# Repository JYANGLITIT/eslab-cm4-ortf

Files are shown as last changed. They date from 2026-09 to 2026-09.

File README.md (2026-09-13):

# ESLab CM4 ORTF v1.1

A compact indoor stereo microphone mount for two Line Audio CM4 microphones, with a fixed nominal ORTF layout, PETG-CF frame and replaceable TPU 95A suspension/liners.

**Free downloads for non-commercial use — CC BY-NC-ND 4.0. No commercial license is granted.** Credit ESLab (Eternal Sound Lab), retain the attribution and license; do not distribute modified versions. See [NOTICE](NOTICE.md) and [license](LICENSE.txt).

## Cable compatibility — required

**Use L-shaped / right-angle 3-pin XLR female connectors at BOTH microphones. Straight XLR connectors interfere with each other in this layout and are not supported.** This restriction was identified by the owner during a V1.0 physical trial on 13 September 2026 and also applies to V1.1, whose only geometry change is the base lettering. Right-angle connector body sizes and cable exit orientations vary; verify clearance with your chosen connectors. No specific cable brand or length has been validated. Keep the cables slack to avoid constraining the suspension.

**接线要求：两只麦克风端都需使用 L 型／直角三芯 XLR 母头。直头会相互干涉，不适用。** 这是 V1.0 实物试装发现的限制，V1.1 仅增加底座刻字，因此同样适用。L 头外壳尺寸与出线方向不同，请核对所选接头的净空；目前未验证具体品牌或长度。

[▶ Watch the 28-second V1.0 physical assembly / quick-release demo](v1.0-physical-demo.mp4) · [28 秒实拍拆装视频](v1.0-physical-demo.mp4)

## V1.0 physical photographs

Photos supplied by the designer on 13 September 2026. These show the assembled **V1.0** mount, without the ESLab / CM4 lettering added in V1.1. The photos show microphones with cables disconnected; they do not demonstrate a particular L-shaped connector fit.

实拍为 **V1.0（未刻字版）**，下载 V1.1 仅增加底座刻字。照片中麦克风未接线，L 型接线要求来自设计者另外的实际试装反馈。

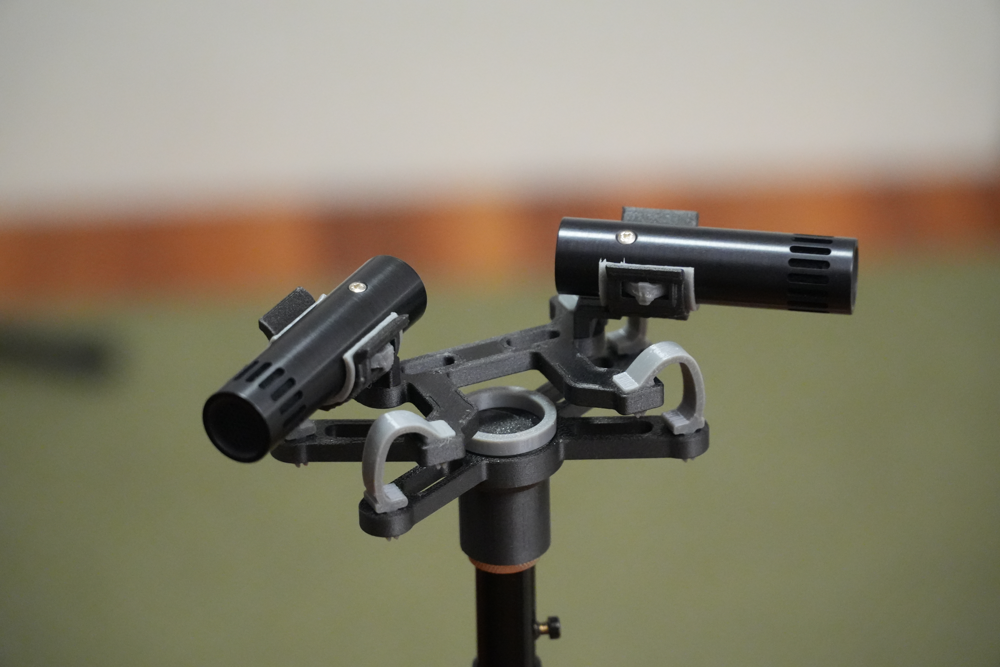
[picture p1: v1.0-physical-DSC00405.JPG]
V1.0 physical print DSC00405


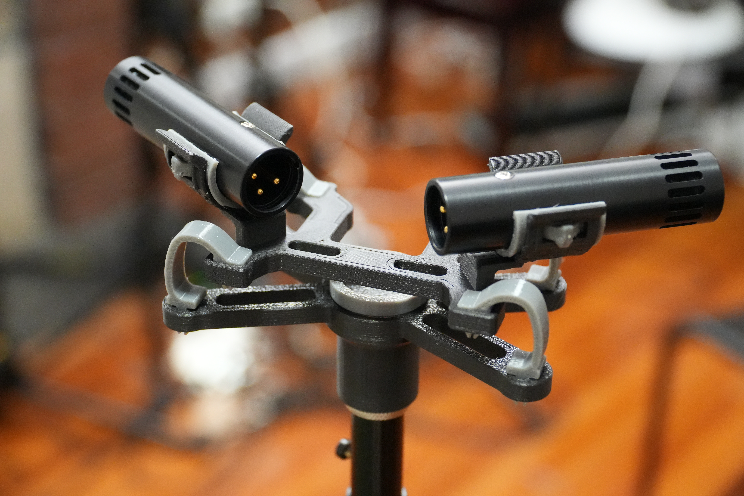
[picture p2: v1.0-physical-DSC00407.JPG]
V1.0 physical print DSC00407


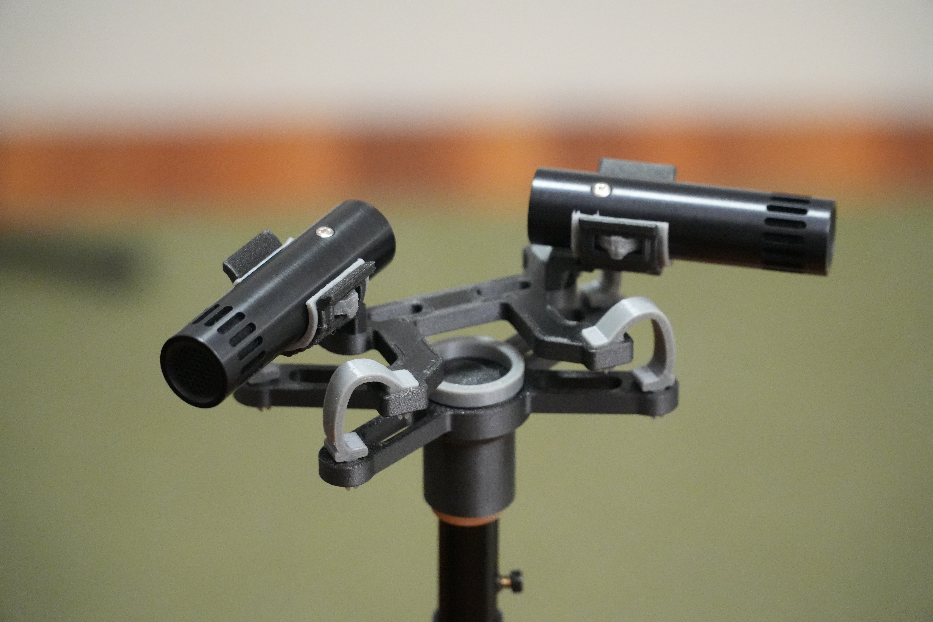
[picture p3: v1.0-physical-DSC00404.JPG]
V1.0 physical print DSC00404


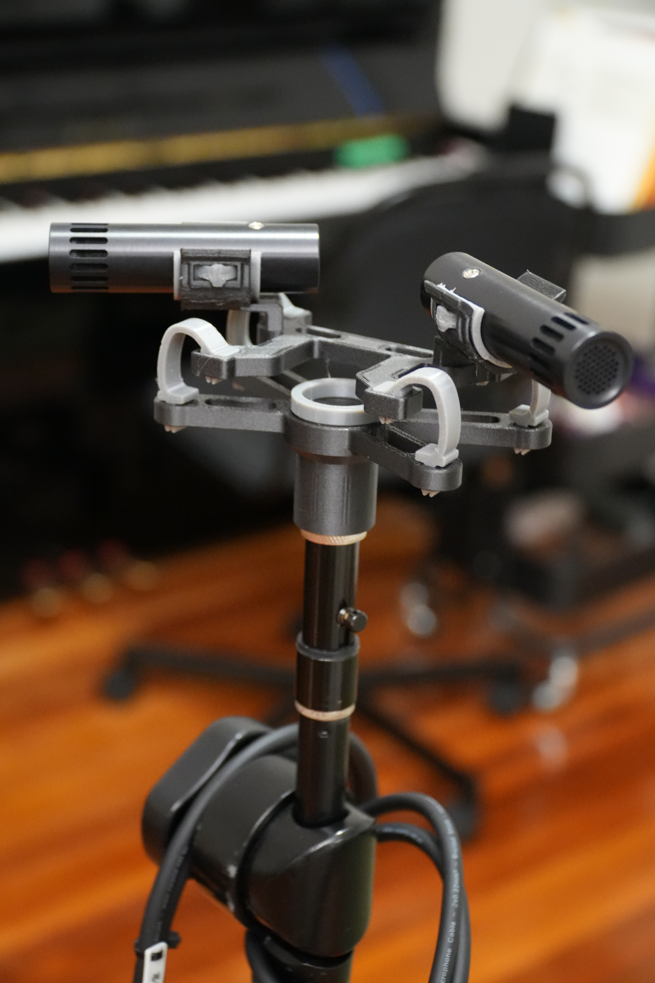
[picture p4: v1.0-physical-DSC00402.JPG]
V1.0 physical print DSC00402


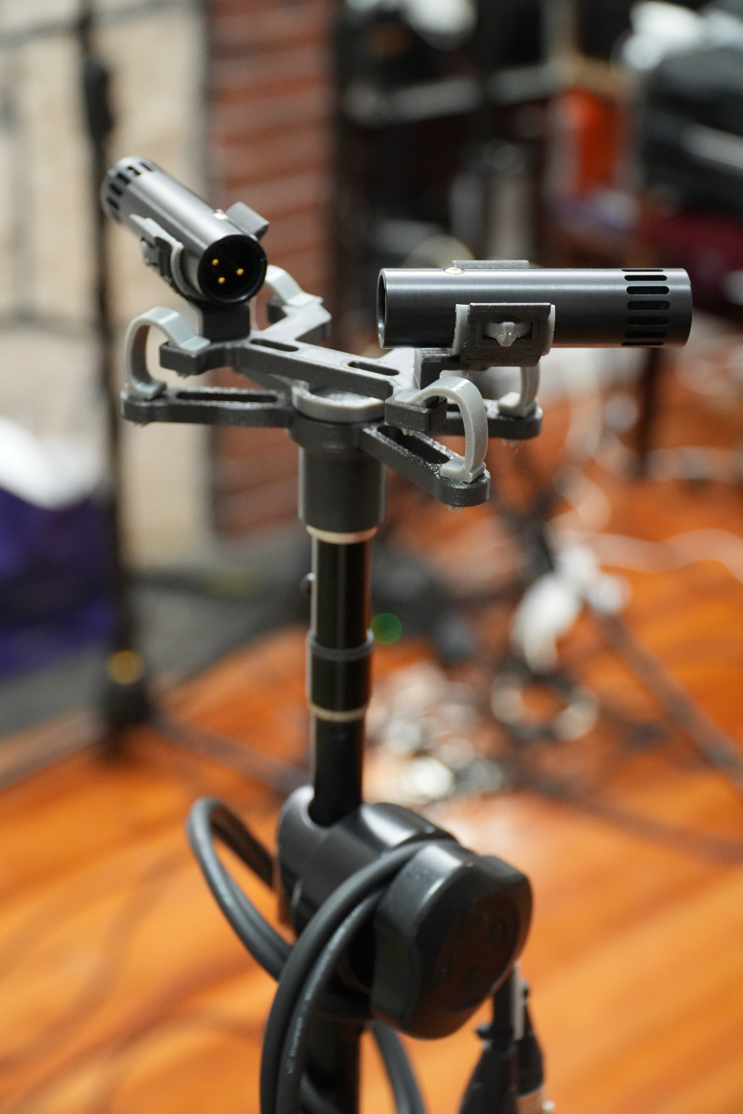
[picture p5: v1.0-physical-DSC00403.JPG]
V1.0 physical print DSC00403


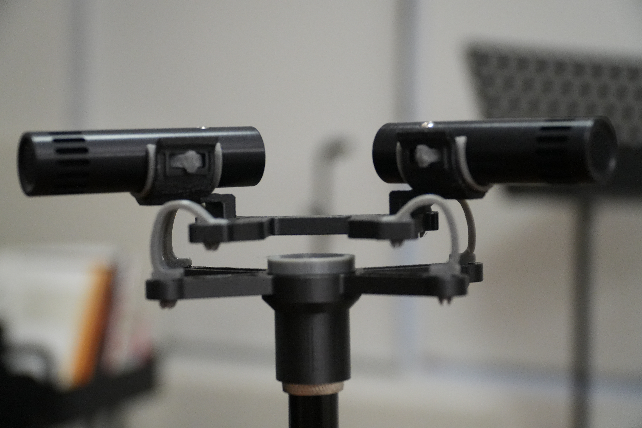
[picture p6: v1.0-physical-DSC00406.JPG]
V1.0 physical print DSC00406


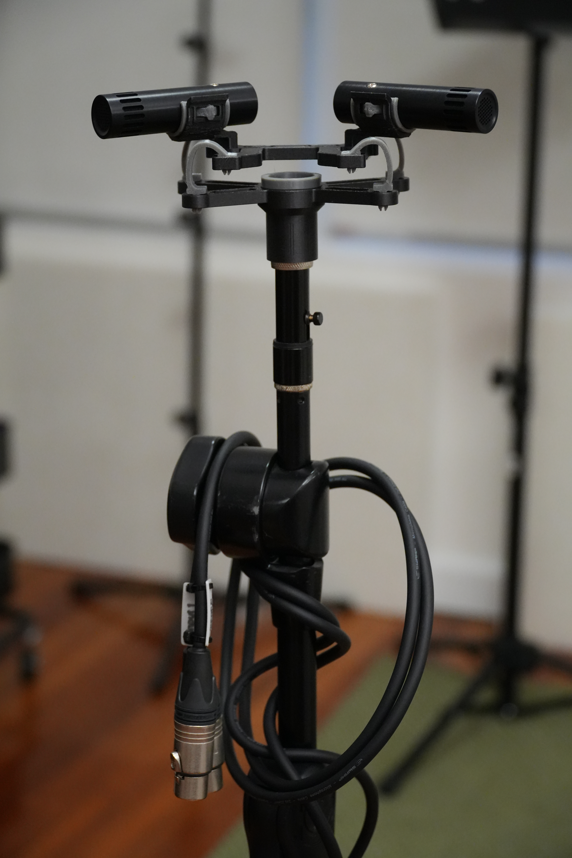
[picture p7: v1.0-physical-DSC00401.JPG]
V1.0 physical print DSC00401


## V1.1 CAD illustration

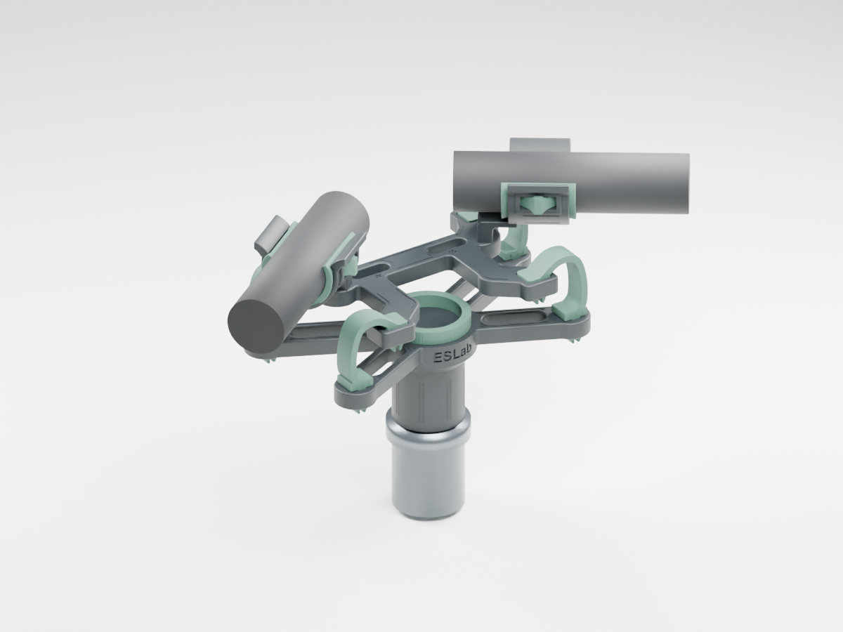
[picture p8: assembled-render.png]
CAD render of the assembled mount; not a photograph


## Download and print

Download [the complete ZIP](ESLab-CM4-ORTF-v1.1-CC-BY-NC-ND.zip), or open [PETG-CF plate](01-PETG-CF-P2S.3mf) and [TPU plate](02-TPU95A-P2S.3mf) as Bambu Studio **projects**, preserving object overrides and orientations. Print each plate once for a complete nine-part set. Individual STL files in this repository are included for other slicers; their orientations match the print baseline.

| P2S 0.4 mm plate | Parts | Material | Supports | Slicer estimate |
|---|---|---|---|---|
| 01-PETG-CF-P2S.3mf | Base + floating carrier (2) | ELEGOO PETG-CF | Carrier only; base disabled via object override | 3h 34m / 42.29 g including support |
| 02-TPU95A-P2S.3mf | Four flexures + two liners + central bumper (7) | ELEGOO TPU 95A | None | 1h 50m / 13.63 g |

Keep **by-layer printing** and 100% model scale. The PETG-CF profile uses 0.16 mm layers, 5 walls and 35% gyroid infill. TPU uses 0.20 mm layers, 3 walls and 100% rectilinear infill. Dimensions/geometry are unchanged by the two-plate arrangement. No machine G-code is distributed. Printer preparation time may differ.

## Branding

The base has real recessed **ESLab** lettering on the front and **CM4** on the rear, approximately 3.8 mm high and 0.5 mm deep. It is included in both the STL and PETG-CF print profile.

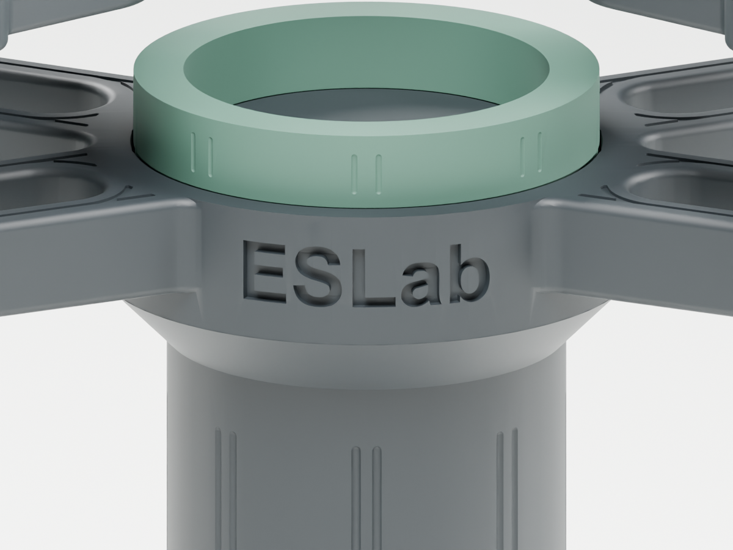
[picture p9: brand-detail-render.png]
Front ESLab engraving render


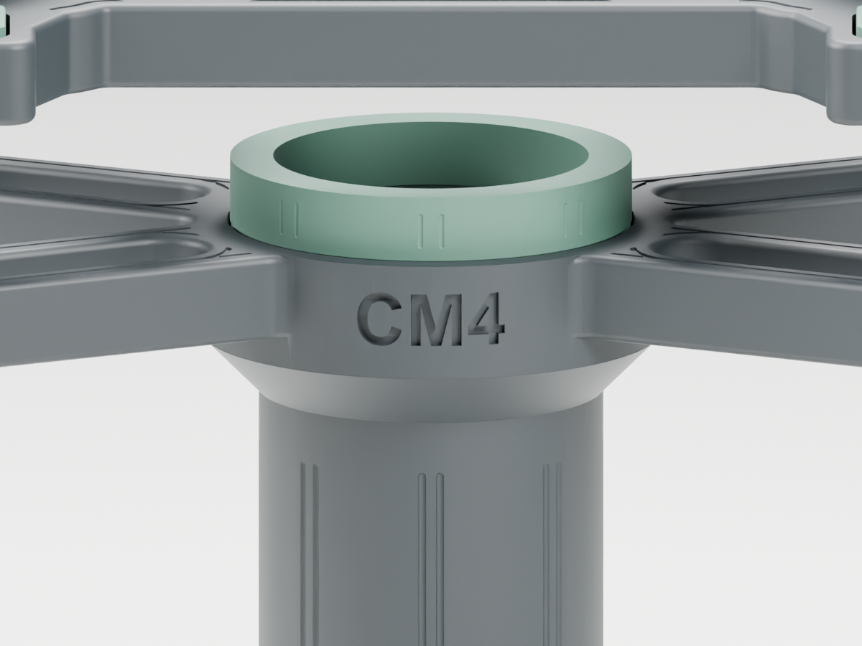
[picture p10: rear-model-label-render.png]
Rear CM4 engraving render


## Intended setup

- Two CM4 bodies: nominal diameter 20 mm, length 77 mm; owner-confirmed mass 30 g each.
- Nominal front reference spacing 170 mm, axis angle 110 degrees. Internal diaphragm setback has not been measured.
- Original On-Stage QK2BC quick-release hardware; printed 5/8-27 female interface uses the owner-tested 0.15 mm radial compensation. Quick-release hardware and microphones are not printable parts in this package.
- Tool-free soft liners and split suspension anchors; intended for indoor piano / concert-hall recording.
- Right-angle XLR connectors are required at both microphones; straight connectors clash. No cable-specific mounting features. Leave cable slack so it does not constrain the floating carrier.

## Assembly

1. Remove the carrier supports and clear strings from all sockets and split anchor slots.
2. Seat the central bumper in the base groove and engage both latches.
3. Install the four flexures, lower ends first. **Longer anchor necks connect to the base; shorter necks connect to the floating carrier.** Curved ribbons bow outward. Align each anchor's long edge with the socket, pinch both split barbs and push through until both rebound. Do not pull on the ribbon.
4. Latch each TPU liner into both carrier windows. Open the soft lips to install the microphones; do not force the PETG-CF clip edges apart.
5. Align the microphone tail to the long witness mark. Short adjacent marks are 1 mm apart. Microphone axial retention is by TPU friction, not a mechanical lock on the microphone body.
6. Attach the original quick release, connect right-angle XLR cables with slack and check that the floating frame is level and does not touch rigid parts during normal loading.

[中文详细装配说明](装配说明.md)

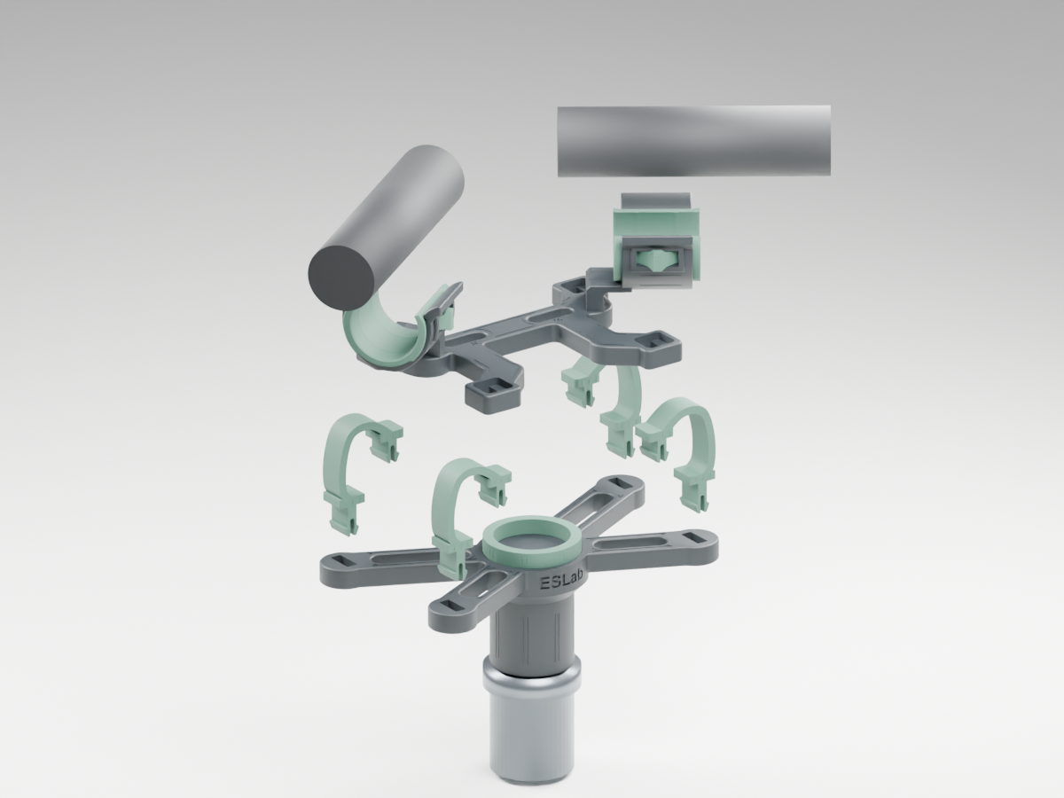
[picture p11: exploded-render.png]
Exploded CAD render, not a photograph


## Validation and limits

This is the **v1.1 frozen print baseline**, geometry ID `99acfbc5fd`. Mesh/assembly checks and both merged-plate slices passed. The owner confirmed the thread fit, liner fit and upper split-anchor coupon fit. The integrated lower anchor has a longer neck and still requires full-assembly fit confirmation. Load deflection, isolation performance, fatigue, creep and drop resistance have not been established by physical tests. V1.0 physical photographs are provided separately in the repository and model gallery; V1.1 CAD renders show the added base lettering. Physical assembly is visible in the V1.0 photos; isolation, fatigue, creep and drop performance remain unmeasured.

If you already have v0.17 hard parts, liners and bumper, v1.0 changed the four suspension flexures; v1.1 additionally engraves ESLab on the front and CM4 on the rear of the base. Other parts are unchanged.

## 中文概述

面向室内钢琴／音乐厅录音的 Line Audio CM4 专用 ORTF 支架。整套九件分两盘打印：PETG-CF 硬件一盘，TPU 95A 减震件和内衬一盘。底座接原装 On-Stage QK2BC 快拆，角度与名义参考间距固定。

**免费非商业使用，禁止商用。采用 CC BY-NC-ND 4.0：转载需署名，不允许分享修改版，私人非商业修改可以。** 这是带非商业限制的设计共享，不宣称为不限制用途的开源硬件。

文件已通过数字模型与切片检查；已确认的试配项目与整机尚未实测项目列在上方。仓库和模型图库另附 V1.0 实拍照片；V1.1 CAD 渲染图展示新增刻字。照片不能证明隔振或耐久性能。

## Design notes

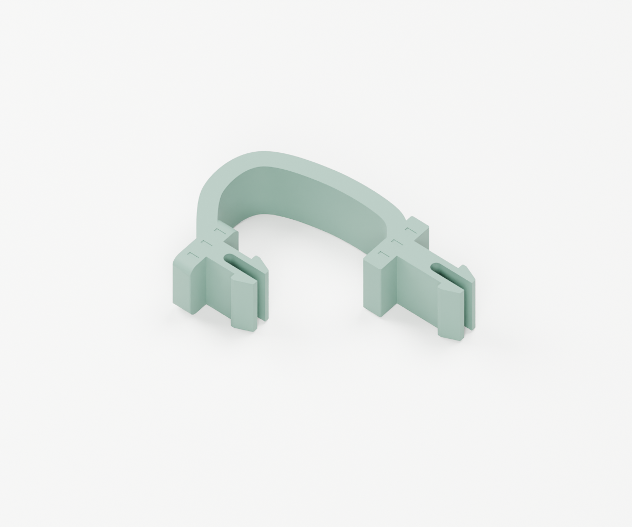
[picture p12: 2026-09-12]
flexure-orientation.png

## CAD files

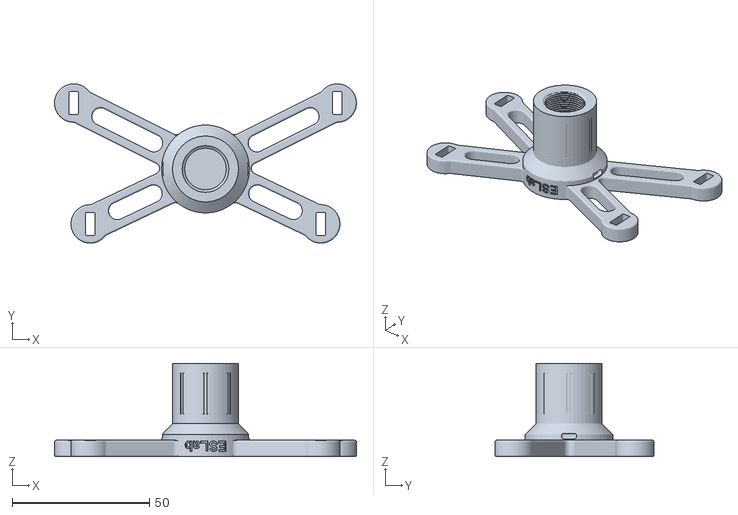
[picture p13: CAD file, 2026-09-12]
01_fixed_PETG_base.stl
110.0 x 58.0 x 34.0

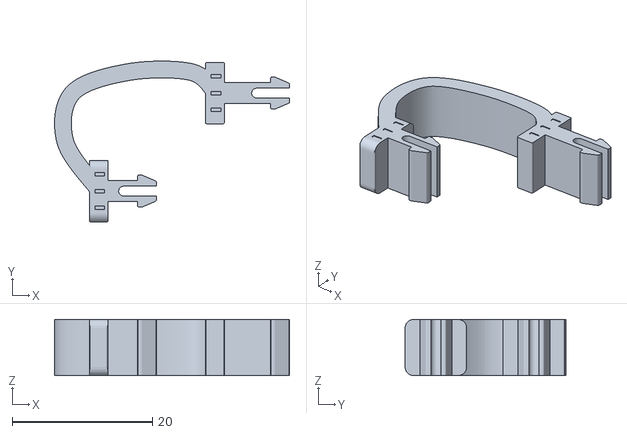
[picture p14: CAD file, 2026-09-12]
04_TPU_keyed_flexure_3.stl
33.6 x 23.0 x 8.00

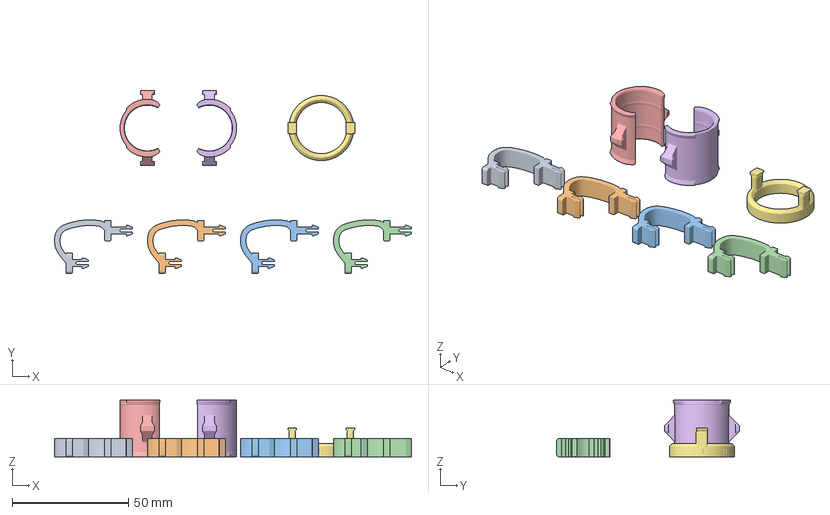
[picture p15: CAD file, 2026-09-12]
02-TPU95A-P2S.3mf
153.6 x 78.6 x 24.4 mm
04_TPU_keyed_flexure_1
04_TPU_keyed_flexure_2
04_TPU_keyed_flexure_3
04_TPU_keyed_flexure_4
03_TPU_clip_liner_L
03_TPU_clip_liner_R
05_TPU_compact_bumper

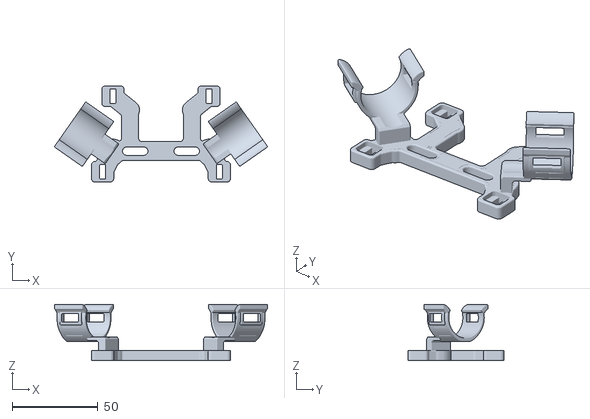
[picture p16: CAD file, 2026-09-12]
02_floating_PETG_carrier_with_snap_clips.stl
124.1 x 56.0 x 32.8

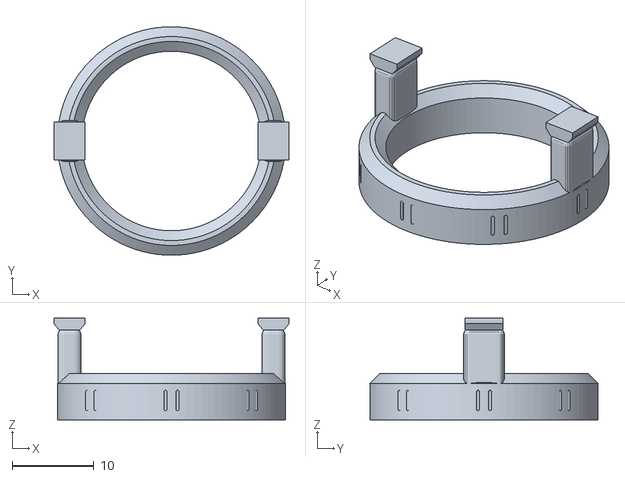
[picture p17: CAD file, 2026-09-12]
05_TPU_compact_bumper.stl
28.8 x 28.0 x 12.5

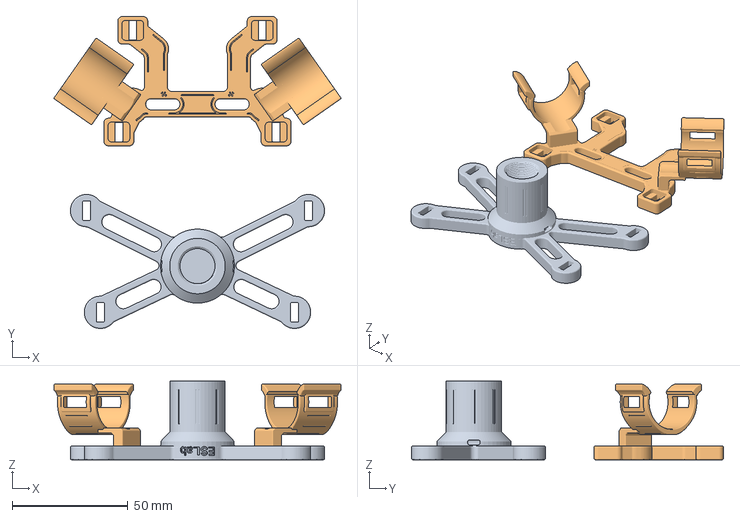
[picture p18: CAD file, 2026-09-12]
01-PETG-CF-P2S.3mf
124.1 x 135.0 x 34.0 mm
01_fixed_PETG_base
02_floating_PETG_carrier_with_snap_clips

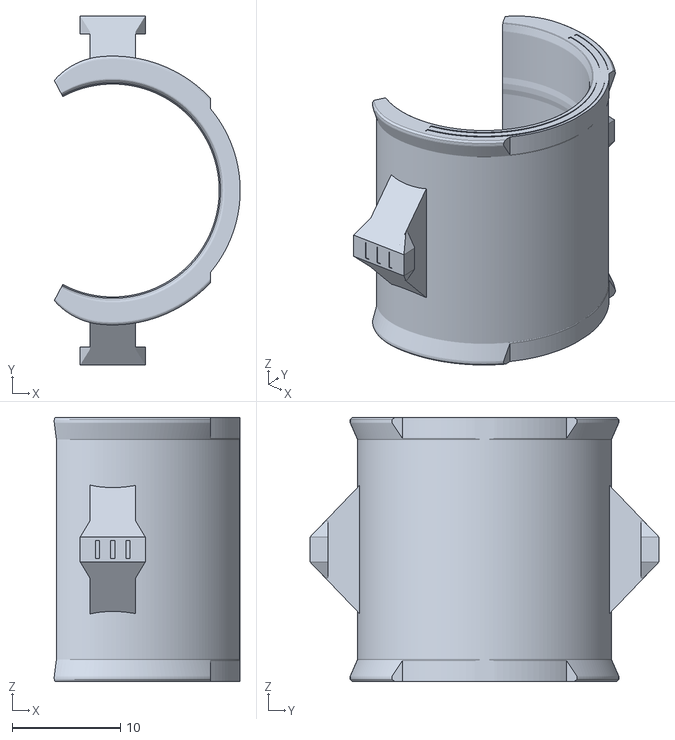
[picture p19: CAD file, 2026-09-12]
03_TPU_clip_liner_R.stl
17.1 x 32.2 x 24.4

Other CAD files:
04_TPU_keyed_flexure_4.stl
04_TPU_keyed_flexure_1.stl
04_TPU_keyed_flexure_2.stl
03_TPU_clip_liner_L.stl

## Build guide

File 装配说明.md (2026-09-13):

# ESLab CM4 ORTF v1.1 — 正式打印定版

本版冻结用于制作的几何和打印配置。材料：ELEGOO PETG-CF、ELEGOO TPU 95A；打印机：Bambu Lab P2S，0.4 mm 喷嘴。几何标识：99acfbc5fd。

“打印定版”代表文件与尺寸已统一；不代表整机隔振、寿命、跌落或长期蠕变已通过测试。

## 原版零件与朝向说明（公开包已合为两盘）

公开包优先打开 `print-profiles` 的两盘 3MF：PETG-CF 硬件一盘，TPU 95A 软胶件一盘。下面按零件说明原有打印朝向；这些朝向在两盘版中保持不变。备用 STL 位于 `STL`。

| 文件 | 材料 | 零件数量 | 朝向与支撑 |
|---|---|---:|---|
| PETG-CF 盘：底座 | PETG-CF | 1 | 已倒置；关闭支撑。环槽、卡脚通道、螺纹起始层有局部桥接，检查其成型。 |
| PETG-CF 盘：双麦骨架 | PETG-CF | 1 | 框架落地、麦夹朝上；开启支撑，主要从平台进入麦夹下方空区。定位窗口顶面仍需桥接。 |
| TPU 盘：四点减震 | TPU 95A | 4 | 宽侧面平放；关闭支撑。每个连接端均为开缝卡头。 |
| TPU 盘：双侧卡扣内衬 | TPU 95A | 2 | 麦轴竖直、C 形端面落地；关闭支撑。采用已确认配合的标准入口尺寸。 |
| TPU 盘：中央缓冲环 | TPU 95A | 1 | 环顶面朝下、卡脚朝上；关闭支撑。 |

成套件：底座 1＋骨架 1＋减震件 4＋内衬 2＋中央环 1。原 On-Stage QK2BC 快拆和 CM4 麦克风为外购实物，不是打印件。无需增加螺钉或其他五金件。

## 本次定版整合

- 四条减震件的上下共八个连接端采用开缝倒钩：最大宽 4.6 mm，中缝 1.4 mm，缝根圆角 0.7 mm。上端使用用户刚确认松紧合适的小试件形状。
- 下端适配 6 mm 厚底座，颈部比上端长 2.4 mm；倒钩与开缝形状保持一致。下端整件插装还需在装配时复核。
- 双侧卡扣内衬保持已确认的尺寸：主体径向厚度约 1.78 mm，标准 62° 入口；不再增减松紧。
- 双麦骨架保留 v0.17 的连续宽边：宽 20 mm、根部名义带厚 3.2 mm、端部 2.8 mm。硬夹窗口宽 12.0 mm。
- 保留底座、轮廓纹路、中央缓冲环及已试配的 5/8-27 螺纹 0.15 mm 径向补偿。

v1.0 更新了四条减震件；v1.1 另外在底座正面增加 ESLab、背面增加 CM4 真实凹刻字。其余零件保持原样。旧底座功能上仍可沿用，需要双面刻字则重打新版底座。v0.18 的小卡头是上端验证试件，不作为成套零件装入整机。

## 接线兼容性（2026-09-13 实物反馈）

**两只麦克风端必须使用 L 型／直角三芯 XLR 母头。直头会相互干涉，不适用于当前 V1.0／V1.1 布局。** 不同 L 头的尺寸和出线方向不同，需确认所选接头的净空。尚未确定具体线材品牌和长度。照片为 V1.0 实物；V1.1 仅增加底座 ESLab／CM4 刻字。

## 装配顺序

1. 清理硬骨架支撑及孔内毛丝，保持卡扣孔的棱边形状。确认开缝卡头中间通缝未被拉丝粘住。
2. 将中央缓冲环放入底座圆槽，两侧卡脚完全就位。缓冲环在正常未下沉状态与浮动骨架应留有间隙。
3. 先装四条减震件的下端，再装上端。**下端颈部较长，连接底座；上端端座圆角与沉台相配，连接浮动骨架。** 对照爆炸图，曲带朝外弯。
4. 每个卡头的 8 mm 长边对准孔的长边，手指捏拢两片倒钩压入；两片都完全穿出后应回弹。不要仅卡住一侧，也不要用拉扯减震带的方法强行装配。
5. 将两只内衬的双侧扣完全卡入硬夹窗口，再拨开 TPU 软唇安装 CM4。不要强掰 PETG-CF 硬边。
6. 麦克风尾端对齐原有中央长刻线。前后短刻线间距 1 mm。刻线是位置参考，麦克风仍靠 TPU 包覆摩擦保持。
7. 底座接上原 On-Stage 快拆。接线后观察浮动骨架下沉和四条减震件是否对称，不应有硬件互相顶住。线材留松弛弯，避免拉住浮动部分。

拆卸卡头时，从孔背面捏拢两片倒钩再退出。装配时若下端仍过紧、卡头无法回弹或存在撕裂，应停止该处强行插入并反馈实际位置。

## 配置保留

| 参数 | PETG-CF | TPU 95A |
|---|---|---|
| 层高 | 0.16 mm | 0.20 mm |
| 墙层数 | 5 | 3 |
| 稀疏填充 | 35% 螺旋体 | 100% 直线 |
| 喷嘴 / 纹理 PEI | 255°C / 70°C | 240°C / 35°C |
| 体积流量上限 | 6 mm³/s | 2 mm³/s |
| 支撑 | 仅硬骨架及备用硬夹试片开启 | 关闭 |

保留文件朝向、材料类型和比例。不要整体缩放、开启模糊皮肤或通过改填充来改变卡扣松紧。耗材状态、流量校准和首层附着仍会影响实物尺寸。

## 验证状态

| 项目 | 依据 |
|---|---|
| 0.15 mm 螺纹补偿 | 用户先前实物试配合适，本版保持 |
| 双侧卡扣内衬 | 用户确认安装与卡紧手感合适，本版保持 |
| 开缝上端卡头试件 | 用户确认测试完成、松紧正好；本版逐个比对八个卡头的相同形状 |
| 下端较长颈部 / 整条减震件 | 名义几何与切片复核；完整装配待实物确认 |
| 加固硬夹 | 几何与装卸净空检查，尚无抗折或疲劳实测 |
| 长期抗滑、蠕变、跌落、减震 | 尚未完成实测 |

本版的数字检查包括：网格闭合与连通、9 个零件的 36 组名义碰撞、8 个连接端与已试件的几何比对、倒钩保持接触、麦克风装卸采样、支撑通道及逐层切片。刚体交叠检查不等于插入力或保持力测量。

两只 CM4 按用户确认 30 g/只，共 60 g。各盘切片用量和时间见根目录 README.md；打印支撑不计入实际浮动装配重量。线材约束和减震件自身参与运动的质量仍需考虑。

ORTF 为名义前端参考间距 170 mm、轴线夹角 110°。内部振膜位置未实测，麦克风端须使用 L 型 XLR 母头；直头会相互干涉。具体 L 头型号尚未选定，不能保证所有 L 头外壳与出线方向均适配。

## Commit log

2026-09-12 Publish CM4 ORTF v1.1 with ESLab and CM4 engraving
    Two material plates, nine STL parts, assembly instructions and actual CAD renders. CC BY-NC-ND 4.0: free non-commercial downloads; no sharing modified versions.
    [01-PETG-CF-P2S.3mf, 01_fixed_PETG_base.stl, 02-TPU95A-P2S.3mf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]
2026-09-13 Add V1.0 physical photos 1–3
2026-09-13 Add V1.0 physical photos 4–5
